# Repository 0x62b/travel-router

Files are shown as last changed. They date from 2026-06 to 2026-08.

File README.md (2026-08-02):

# CM5 Router
A carrier board for Raspberry Pi CM5 with dual 1G ethernet and wifi that turns it into a portable travel router. Also supports LTE/5G dongle over USB ([example](https://www.telstra.com.au/internet/mobile-broadband/prepaid/4gx-mf833v-usb-2026)). Using OpenWRT for firmware. [onshape link](https://cad.onshape.com/documents/ac7af34a2b8f11fe38ae6564/w/c8135ace2385cb6ff4c9d748/e/cb10deb1874ff2f63763bead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)

Functions:
* Dual 1G ethernet
* Wifi through onboard antenna and USB
* Support for LTE/5G dongle over USB
* 80x80mm board, portable case

## Motivation
I had a spare CM5 lying around, as any normal person would (/s). I also wanted to learn high-speed signal routing, so making a CM5 carrier board would be a perfect excuse. Also, I needed a travel router, so I figured that this would be a fun project to make.

As you can see by the cost breakdown later, this project is not economical at all if you want to build it from scratch and don't have a CM5 already. However, if you already have a CM5, this can be used just like any other carrier board.

## Repo Structure
`cad`: CAD files, 3D models, case design\
`pcb`: KiCad design files\
`production`: Production files (gerbers and case models)\
`bom.csv`: BOM\
`lcsc.csv`: LCSC BOM list export

There are some 3D model files in the design that are not in the KiCad libraries. Since there's probably some kind of restrictions on me putting them in this repo, here is how you can get them yourself.
* CM5 model can be found from [here](https://pip.raspberrypi.com/categories/1096-design-files)
* RTL8111H is LCSC part C2761340
* HDMI port is LCSC part C5289795
* Switch is LCSC part C431540
* Any remaining models not listed here should be in the Raspberry Pi CM5IO files
LCSC part numbers can be used to get 3D models through [easyeda2kicad](https://github.com/uPesy/easyeda2kicad.py)

You may also notice that the CM5 model is missing from the Onshape assembly. This is because it was already extremely laggy after adding this model in KiCad, so I don't want to know how bad it'll be in onshape

## Cost breakdown
LCSC: 34.59 USD parts + 8.1 USD shipping = 42.69 USD\
Other (parts I own but are still in the BOM):
* Heatsink/fan assembly: 15 USD from amazon / 7 USD + shipping from Waveshare
* CM5 2GB/32GB w/ wireless: 97.50 USD from DigiKey

PCB: 7 USD + 1.50 USD shipping = 8.50 USD\
Total: 51.19 USD (parts I need) // 163.69 USD (total)

## Assembly
A kind of oversimplified guide to building this project if you want to replicate it for some reason

### Soldering
This can't really be made much more simple. It is a very hard board to handsolder, even with decent equipment. There are very fine-pitch QFNs and connectors, along with some 0201 passives (decoupling caps). If you are building this for some reason and really want to solder the board yourself, start with the smaller passives and work up to bigger parts, doing the big through hole components last. If you want to recreate this project, PCBA may be a good choice, at least for part of the board.

### 3D printing
This should be a very easy print. No specific print settings or filament are required, except for supports for the ports on the bottom case.

### Full assembly
Prerequisites: solder the PCB, print the case, collect all other required parts
1. Place the spacers for the heatsink/fan assembly aligned with the screw holes in the PCB
2. Attach the CM5 to the carrier board
3. Screw in the assembly from the bottom using the included screws
4. Insert a CR2032 RTC battery into the slot on the carrier board
5. Place the assembled PCB into the case and screw into place using M3x4 screws
6. Prepare the power button and affix it to the hole, then plug it into the header on the PCB
7. Before closing the case, attach an HDMI cable and flash OpenWRT onto the device
8. Configure OpenWRT based on the below section
9. Disconnect the HDMI cable and screw in the lid using M2x10 screws

The reasoning for the HDMI port only being accessible when the device is disassembled is that-
* It is only used for flashing/configuring/debugging the device, which would usually occur in a disassembled state anyway
* Having the port inside removes the need for yet another opening in the case, better protecting it from ESD etc.
* This footprint allowed for MUCH easier routing during the design phase.

## Configuring OpenWRT
(this is a wip as i try to figure out how this software works as I actually build the project)\
(no i do not know. once i finish building this thing, assuming it works, ill have to wing it)\
The basic gist of it is that you want one of the Ethernet ports configured as a WAN port, one as a LAN port, and wifi set up as a bridge, where you can get a "WAN" network over wifi and broadcast it as "LAN". If you have a USB cellular modem, you can also add that.

The wired interfaces configuration _should_ be relatively self-explanatory.
Follow this [guide](https://www.linuxscrew.com/openwrt-network-setup) for the Wifi bridge part.
Follow this [guide](https://ten64doc.traverse.com.au/applications/cellular/) for the cellular modem part.

## Images
### Schematic





### PCB render


### Full render


### Zine page


update 02/08/26: it's still not built because LCSC is out of stock of many components in my bom </3 rest of the project/fw info will go up when i can actually get the board and parts

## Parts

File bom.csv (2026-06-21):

Name | Unit Price (USD) | Quantity | Extended Price (USD) | Notes | Link
HX PH254-01-02-Z-L11.5 (hanxia) | 0.0130 | 50 | 0.65 | MOQ=50 | https://www.lcsc.com/product-detail/C52016390.html
X322525MOB4SI (YXC) | 0.1040 | 5 | 0.52 | MOQ=5 | https://www.lcsc.com/product-detail/C9006.html
RTL8111H-CG (REALTEK) | 1.9971 | 1 | 2.00 |  | https://www.lcsc.com/product-detail/C2761340.html
LPJG0926HENL (LINK-PP) | 3.8943 | 2 | 7.79 |  | https://www.lcsc.com/product-detail/C22457393.html
TPD4EUSB30DQAR (TI) | 0.4490 | 5 | 2.25 | MOQ=5 | https://www.lcsc.com/product-detail/C90627.html
476591100 (MOLEX) | 1.5875 | 1 | 1.59 |  | https://www.lcsc.com/product-detail/C5289795.html
RT9742SNGV (RICHTEK) | 0.4763 | 1 | 0.48 |  | https://www.lcsc.com/product-detail/C3235509.html
AP2553W6-7 (DIODES) | 0.2372 | 5 | 1.19 | MOQ=5 | https://www.lcsc.com/product-detail/C212302.html
TPD2E2U06DCKR (TI) | 0.1532 | 5 | 0.77 | MOQ=5 | https://www.lcsc.com/product-detail/C1855726.html
MSK12C02-HB (SHOU HAN) | 0.0582 | 10 | 0.58 | MOQ=10 | https://www.lcsc.com/product-detail/C431541.html
RT0402BRD072K49L (YAGEO) | 0.0256 | 20 | 0.51 | MOQ=20 | https://www.lcsc.com/product-detail/C852700.html
RT0603BRD071KL (YAGEO) | 0.0237 | 20 | 0.47 | MOQ=20 | https://www.lcsc.com/product-detail/C110776.html
RT0603BRD0715KL (YAGEO) | 0.0297 | 20 | 0.59 | MOQ=20 | https://www.lcsc.com/product-detail/C326733.html
10164227-1001A1RLF (Amphenol) | 1.7712 | 2 | 3.54 |  | https://www.lcsc.com/product-detail/C6782225.html
3034 (Keystone) | 0.3552 | 1 | 0.36 |  | https://www.lcsc.com/product-detail/C5199422.html
BM04B-SRSS-TB(LF)(SN) (JST) | 0.2322 | 5 | 1.16 | MOQ=5 | https://www.lcsc.com/product-detail/C160390.html
USB-269-BRW (XUNPU) | 0.2944 | 5 | 1.47 | MOQ=5 | https://www.lcsc.com/product-detail/C720548.html
TYPE-C-31-M-12 (Korean Hroparts Elec) | 0.1857 | 5 | 0.93 | MOQ=5 | https://www.lcsc.com/product-detail/C165948.html
XL-1608UGC-04 (XINGLIGHT) | 0.0050 | 100 | 0.50 | MOQ=100 | https://www.lcsc.com/product-detail/C965804.html
XL-1608SURC-06 (XINGLIGHT) | 0.0035 | 100 | 0.35 | MOQ=100 | https://www.lcsc.com/product-detail/C965799.html
CC0402JRNPO9BN120 (YAGEO) | 0.0027 | 100 | 0.27 | MOQ=100 | https://www.lcsc.com/product-detail/C106201.html
GRM035R60J475ME15D (muRata) | 0.0732 | 10 | 0.73 | MOQ=10 | https://www.lcsc.com/product-detail/C335103.html
CL03A104KO3NNNC (Samsung Electro-Mechanics) | 0.0029 | 100 | 0.29 | MOQ=100 | https://www.lcsc.com/product-detail/C307380.html
CL05B104KB54PNC (Samsung Electro-Mechanics) | 0.0077 | 100 | 0.77 | MOQ=100 | https://www.lcsc.com/product-detail/C307331.html
EEEFTH101XAP (PANASONIC) | 0.3918 | 5 | 1.96 | MOQ=5 | https://www.lcsc.com/product-detail/C165974.html
CL10A106KO8NQNC (Samsung Electro-Mechanics) | 0.0433 | 10 | 0.43 | MOQ=10 | https://www.lcsc.com/product-detail/C962136.html
CL10B104KB8NNNC (Samsung Electro-Mechanics) | 0.0115 | 100 | 1.15 | MOQ=100 | https://www.lcsc.com/product-detail/C1591.html
CR2032 battery | 0 | 1 | 0 | owned | N/A
Waveshare CM5 heatsink/fan assembly | 0 | 1 | 0 | owned - link is amazon as waveshare shipping expensive | https://www.amazon.com.au/Fan-Dedicated-3007-Compatible-Adjustable/dp/B0DPMQZ4Z2
Raspberry Pi CM5 | 0 | 1 | 0 | owned | https://www.raspberrypi.com/products/compute-module-5/
10mm 2pin momentary push button | 0 | 1 | 0 | owned - link is example of button | https://www.amazon.com.au/VGOL-Button-Compatible-Applications-Limited/dp/B0GFBBVC7T
PCB | 8.5 | 1 | 8.5 | price for 5 | https://jlcpcb.com
M3x4 screws | 0 | 4 | 0 | owned | -
M2x10 screws | 0 | 4 | 0 | owned | -

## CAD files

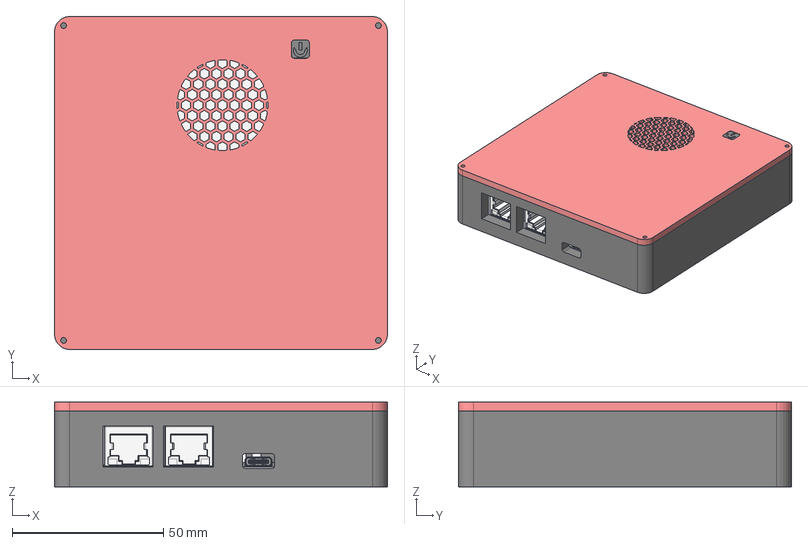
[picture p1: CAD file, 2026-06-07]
cad/router full assembly.step
110.0 x 110.0 x 28.0 mm

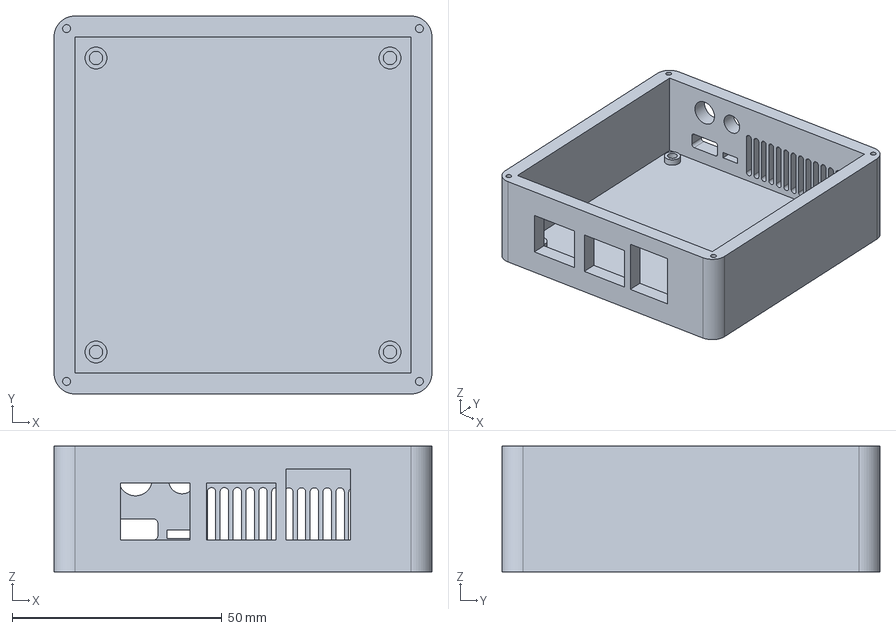
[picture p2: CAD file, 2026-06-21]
cad/router bottom case.step
90.0 x 90.0 x 30.0 mm

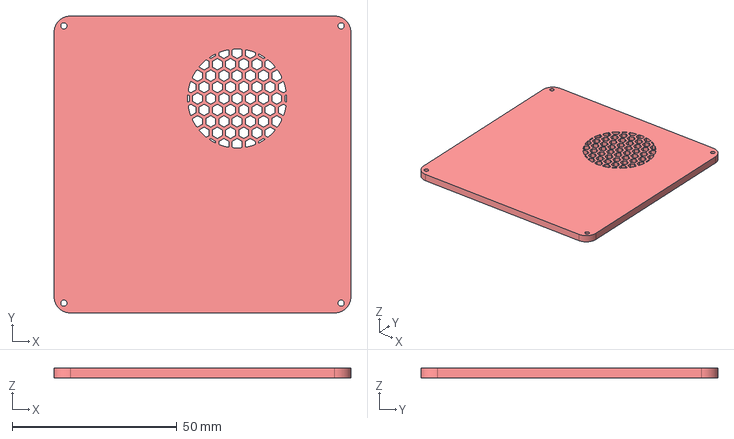
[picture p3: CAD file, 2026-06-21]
cad/router top case.step
90.0 x 90.0 x 3.00 mm

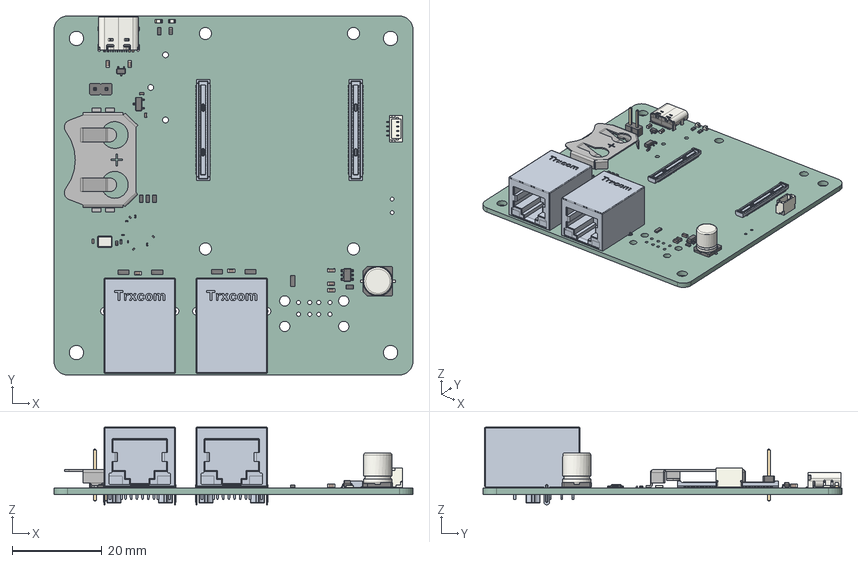
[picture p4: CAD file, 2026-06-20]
cad/board.step
80.0 x 80.0 x 17.3 mm
C_0603_1608Metric x 7
C_0402_1005Metric x 4
R_0603_1608Metric x 6
C_0201_0603Metric x 8
USON_10_25x10mm_Pitch05mm x 5
BatteryHolder_Keystone_3034_1x20mm
LED_0603_1608Metric x 2
PinHeader_1x02_P254mm_Vertical
SOT-23-6
C_Elec_63x77
SOT-323_SC-70
SOT-23-3
TRJG0926HENL-S x 2
10164227-1001A1RLF x 2
USB_C_Receptacle_16P_TopMnt_Horizontal_GCT_USB4105-xx-A
JST_SH_BM04B-SRSS-TB_1x04-1MP_P1.00mm_Vertical
Crystal_SMD_3225-4Pin_3.2x2.5mm
R_0402_1005Metric
travel-router_PCB

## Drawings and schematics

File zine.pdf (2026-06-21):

# CM5 Router

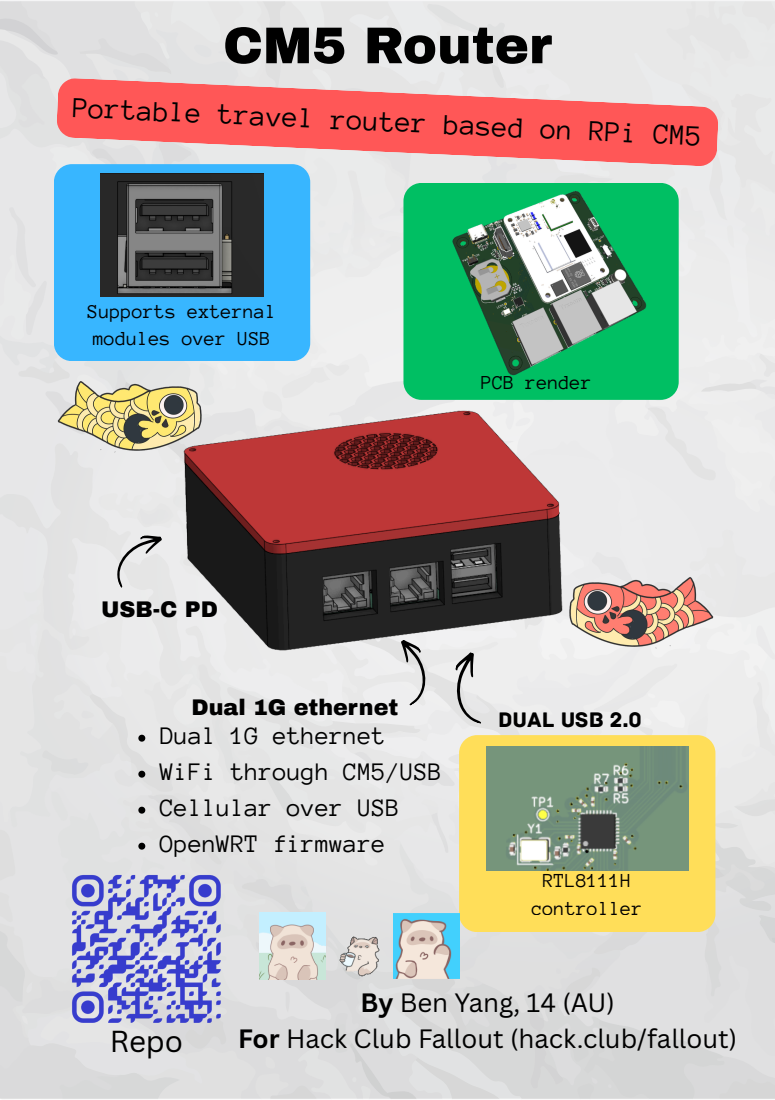
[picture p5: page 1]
Dual USB 2.0; RTL8111H controller; Repo; USB-C PD; PCB render

Portable travel router based on RPi CM5

Supports external
modules over USB

Dual 1G ethernet
WiFi through CM5/USB
Cellular over USB
OpenWRT firmware

By Ben Yang, 14 (AU)

For Hack Club Fallout (hack.club/fallout)

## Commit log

2026-05-31 production files
    [travel-router-B_Cu.gbr, travel-router-B_Mask.gbr, travel-router-B_Paste.gbr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]
2026-06-07 add case files
    [router bottom case.step, router power button.step, router top case.step]
2026-06-08 pcb stuff
    [travel-router.kicad_pcb]
2026-06-08 board step
    [board.step]
2026-06-13 thing thing thing
    [cm5_gpio.kicad_sch, cm5_highspeed.kicad_sch, cm5_pcie.kicad_sch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]
2026-06-14 pcb for now
    [cm5_gpio.kicad_sch, cm5_highspeed.kicad_sch, cm5_pcie.kicad_sch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]
2026-06-17 layout changes
    [cm5_gpio.kicad_sch, cm5_highspeed.kicad_sch, cm5_pcie.kicad_sch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]
2026-06-17 stitching via
    [travel-router.kicad_pcb]
2026-06-19 (probably) final pcb
    [travel-router.kicad_pcb]
2026-06-19 update production files
    [travel-router-B_Cu.gbr, travel-router-B_Mask.gbr, travel-router-B_Paste.gbr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]
2026-06-19 updated bom
    [bom.csv, lcsc.csv]
2026-06-19 fix box position
    [cm5_pcie.kicad_sch]
2026-06-19 add button to bom
    [bom.csv]
2026-06-20 create new cad exports
    [board-lowres.step]
2026-06-21 updates to silkscreen/models
    [travel-router-B_Cu.gbr, travel-router-B_Mask.gbr, travel-router-B_Paste.gbr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]
2026-06-21 add new gerbers to zip
2026-06-21 new board assembly
2026-06-21 remove unused assembly
    [board-lowres.step]
2026-06-21 new cad files
    [router bottom case.step, router power button.step, router top case.step]
2026-06-21 remove unneeded 3mf
    [router.3mf]
2026-06-21 add button to assembly
